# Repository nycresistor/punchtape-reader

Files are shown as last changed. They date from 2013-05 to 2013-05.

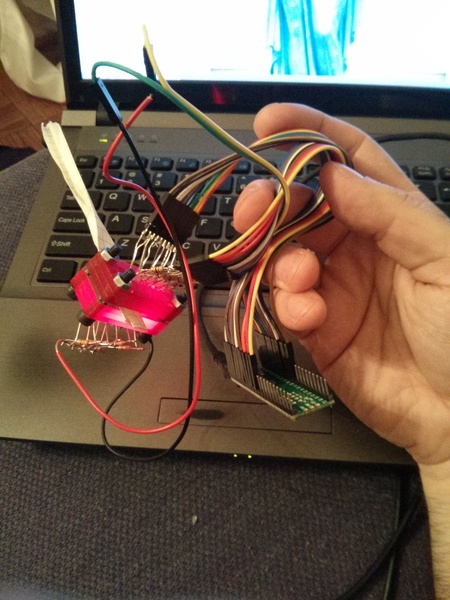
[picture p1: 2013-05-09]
circuit.jpg

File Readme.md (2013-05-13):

Hardware
--------

punchtape.dxf has the basic mechanical design of the read head. The head is bolted together with M3 hardware.

boards/5mm-phototransistors contains Eagle CAD files for the LED emitter and phototransistor boards.

Software
--------

The reader is implemented as an Arduino sketch in punchtape-reader/punchtape-reader.ino. I'm using a Teensy++ 2.0
at present but it should work with any ordinary Arduino variant. You'll have to alter the pin assignments at the top
of the file, though.

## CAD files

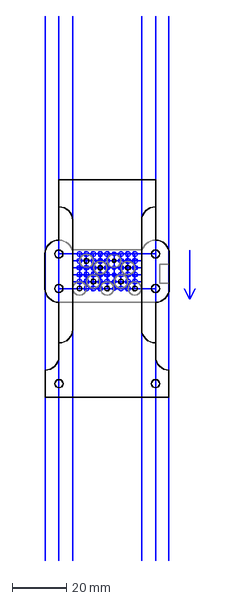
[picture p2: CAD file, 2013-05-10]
punchtape.dxf
55.2 x 200.0 mm

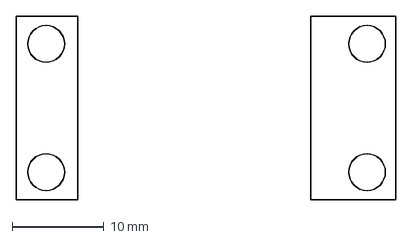
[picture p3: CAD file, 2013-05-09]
punchtape-channel.dxf
41.4 x 20.0 mm

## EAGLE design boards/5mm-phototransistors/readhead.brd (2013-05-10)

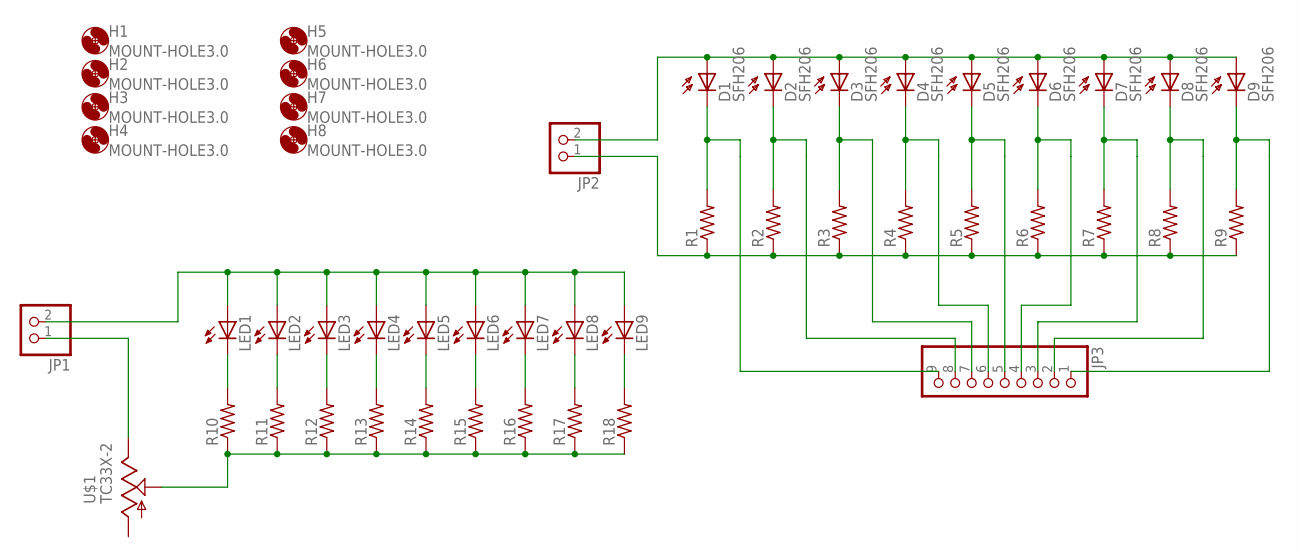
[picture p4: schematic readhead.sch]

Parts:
D1, D2, D3, D4, D5, D6, D7, D8, D9: SFH206
H1, H2, H3, H4, H5, H6, H7, H8: MOUNT-HOLE3.0; 3,0
JP1, JP2: PINHD-1X2; 1X02
JP3: PINHD-1X9; 1X09
LED1, LED2, LED3, LED4, LED5, LED6, LED7, LED8, LED9: LED5MM
R1, R2, R3, R4, R5, R6, R7, R8, R9, R10, R11, R12, R13, R14, R15, R16, R17, R18: R-US_R0805; R0805
U$1: TC33X-2

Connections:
unnamed: LED1.K (C), R10.2
unnamed: LED2.K (C), R11.2
unnamed: LED3.K (C), R12.2
unnamed: LED4.K (C), R13.2
unnamed: LED5.K (C), R14.2
unnamed: LED6.K (C), R15.2
unnamed: LED7.K (C), R16.2
unnamed: LED8.K (C), R17.2
unnamed: LED9.K (C), R18.2
unnamed: D1.K (C), JP3.9, R1.2
unnamed: D2.K (C), JP3.8, R2.2
unnamed: D3.K (C), JP3.7, R3.2
unnamed: D4.K (C), JP3.6, R4.2
unnamed: D5.K (C), JP3.5, R5.2
unnamed: D6.K (C), JP3.4, R6.2
unnamed: D7.K (C), JP3.3, R7.2
unnamed: D8.K (C), JP3.2, R8.2
unnamed: D9.K (C), JP3.1, R9.2
unnamed: JP2.1, R1.1, R2.1, R3.1, R4.1, R5.1, R6.1, R7.1, R8.1, R9.1
unnamed: D1.A, D2.A, D3.A, D4.A, D5.A, D6.A, D7.A, D8.A, D9.A, JP2.2
unnamed: JP1.2, LED1.A, LED2.A, LED3.A, LED4.A, LED5.A, LED6.A, LED7.A, LED8.A, LED9.A
unnamed: R10.1, R11.1, R12.1, R13.1, R14.1, R15.1, R16.1, R17.1, R18.1, U$1.P$2 (S)
unnamed: JP1.1, U$1.P$3 (E)

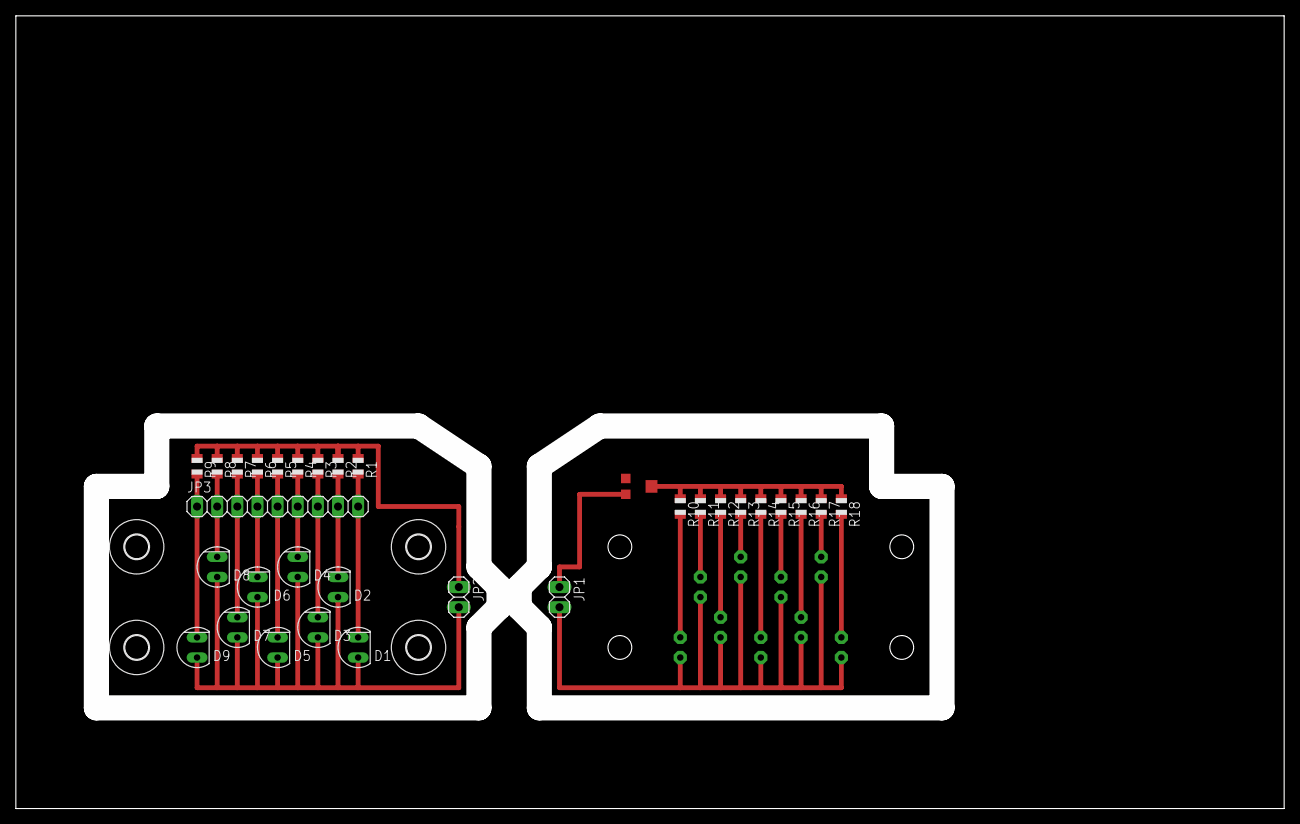
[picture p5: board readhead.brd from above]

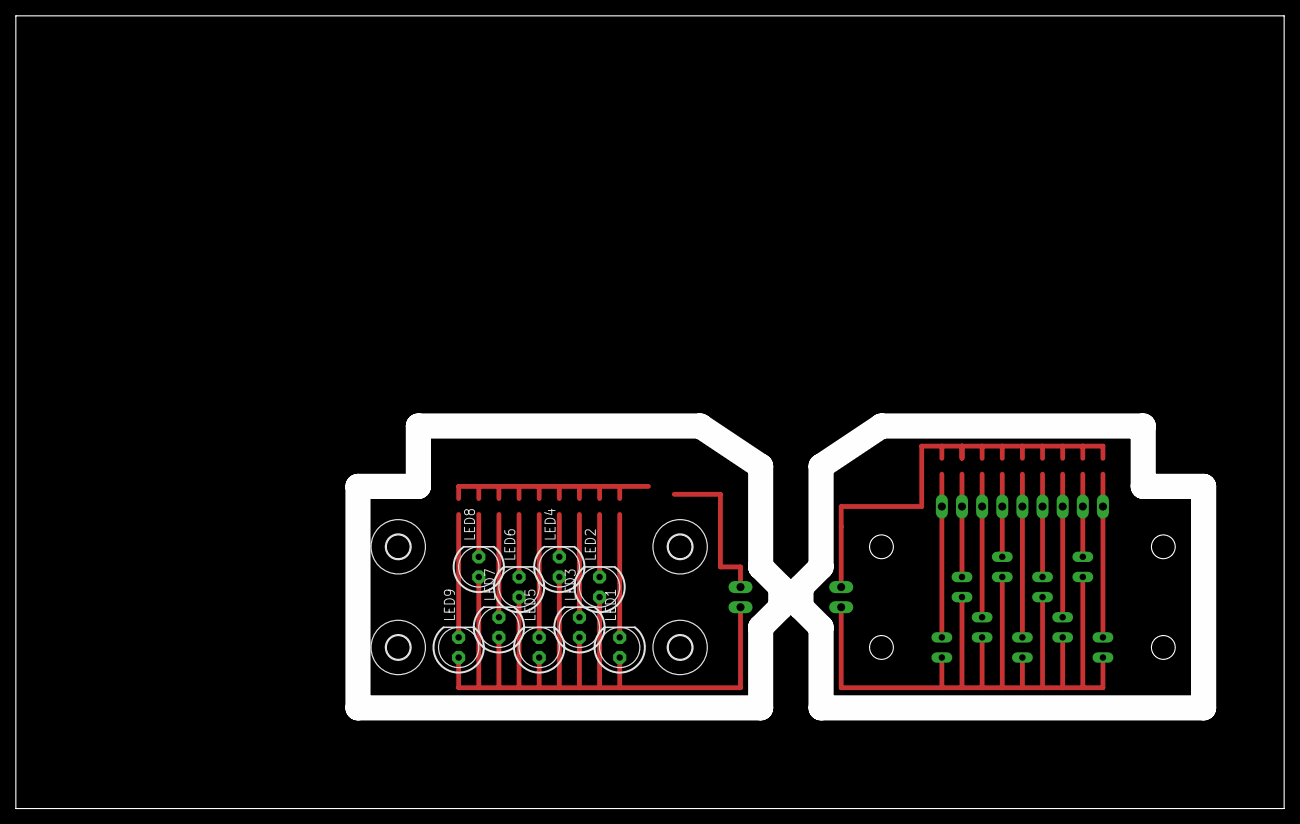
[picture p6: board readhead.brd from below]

Board: 2 copper layers, 160.0 x 100.0 mm, 48 parts (13 on the bottom side), 23 nets.

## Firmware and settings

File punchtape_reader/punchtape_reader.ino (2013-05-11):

#include <stdint.h>

const int SPROCKET_PIN = 21;
const int CHANNEL_COUNT = 8;
const int channels[] = { 26, 25, 24, 23, 22, 20, 19, 18 };

void setup()
{
  Serial.begin(115200);
  Serial.println("Initialized, starting scans");
  for (int i = 0; i < CHANNEL_COUNT; i++) {
    pinMode(channels[i],INPUT);
    digitalWrite(channels[i],LOW);
  }
  pinMode(SPROCKET_PIN,INPUT);
  digitalWrite(SPROCKET_PIN,LOW);
}

const int CONSENSUS_PASSES = 5;

inline bool checkSprocket() {
  return digitalRead(SPROCKET_PIN) != LOW;
}

void waitForSprocket(bool val) {
  // wait for sprocket pin to go to given value.
  while (checkSprocket() != val);
}

uint8_t readHoles() {
  // read all eight bits.
  uint8_t c = 0;  
  for (int i = 0; i < CHANNEL_COUNT; i++) {
    c <<= 1;
    c |= (digitalRead(channels[i]) == LOW)?0:1;
  }
  
  return c;
}

char buffer[5];

void loop()
{
  waitForSprocket(true);
  for (int i = 4; i > 0; i--) {
    buffer[i] = buffer[i-1];
  }
  buffer[0] = readHoles();
  char out = (buffer[0] & 0x40) |
    (buffer[1] & 0x12) |
    (buffer[3] & 0x24) |
    (buffer[4] & 0x89);
  /*  
  Serial.print('|');
  for (int i = 0; i < 8; i++) {
    Serial.print((out&(1<<i))==0?' ':'#');
  }
  Serial.print("|  ");*/
  char c = out & 0x7F;
  //if (c > 32) Serial.print(c); else Serial.print(" ");
  Serial.print(out);
  Serial.flush();
  //Serial.print(" ");
  //Serial.println(((int)out&0xff),HEX);
  waitForSprocket(false);
}

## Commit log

2013-05-09 some futzing around to increase response time don't use pin 6; there's already an LED on it on the teensy 2++
2013-05-09 add detailed instructions for building circuit
2013-05-10 current version; works with pathetic led-led version of the reader.
2013-05-10 5mm leds (the phototransistors we have...), new pattern
    [punchtape.dxf]
2013-05-10 made boards for new hardware; finished mechanical design for read head
    [punchtape.dxf, readhead.brd, readhead.sch]
